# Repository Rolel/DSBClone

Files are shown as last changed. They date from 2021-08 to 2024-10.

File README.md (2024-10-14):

# DSB Clone
This is a replacement board for the SEGA Digital Sound Boards 1 and 2 used on several SEGA arcade games.

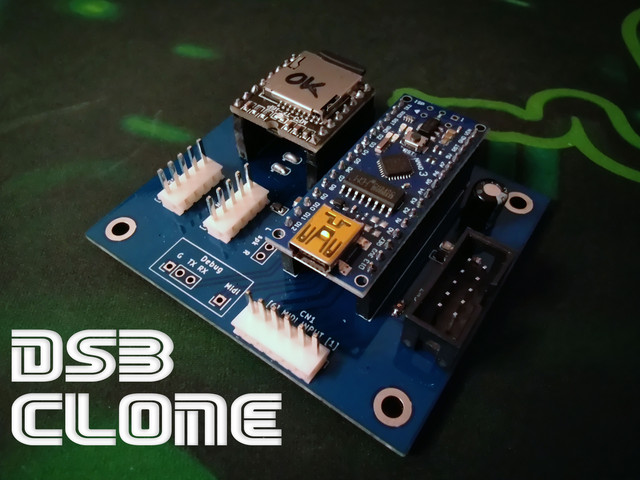
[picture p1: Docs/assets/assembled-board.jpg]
Assembled DSBClone board


# Historical background

The SEGA Digital Sound Boards 1 and 2 are dedicated to playing music (the BGMs) on several SEGA games. The music is stored in maskroms specific to each game. It is a card separate from the main stack of the game, sometimes located in its own cage.

They bear the following references: *837-10084 DIGITAL AUDIO BD SEGA 1993, 171-6614B PC BD, Sticker: 837-12941* and *837-12273 DIGITAL SOUND BD 2 SEGA 1995, 171-7165D PC BD, Sticker: 837-12273-92, Sticker: 837-13376*. These original cards are not very reliable and become difficult to find at a reasonable price.

They were used on the following games:

* First version (DSB1):
  * Daytona USA
  * Desert Tank
  * Manx TT Deluxe
  * Scud Race / Super GT (Model 3 Step 1.5)
  * Sega Rally Deluxe
  * Sega Touring Cars (Model 2C CRX)
  * Star Wars Arcade (Model 1)
  * Virtua Cop
  * Virtua Fighter
  * Virtua Racing
  * Wing Wars

*Please note that Daytona USA, Virtua Racing, Virtua Fighter, Wing War & Star Wars Arcade use DSB1 with an addon board in charge of playing sounds. The DSBclone doesn't handle this. As a result I suggest you avoid clone for such games and **DSB1 support is disabled by default in source code**.*

* Second version (DSB2):
  * Daytona 2
  * Lost World
  * Sega Rally 2
  * Spikeout
  * Spikeout FE
  * Star Wars Trilogy
  * Top Skater

# Features

* Playback of MP3 and WAV files stored on a microSD card
* Plug'n'Play: no modification of the wiring
* Track listing can be modified simply by renumbering the files
* Output volume identical to the original DSB
* Reprogrammable firmware: based on an Arduino Nano
* 24-bit DAC, DR 90dB, SNR 85 dB
* Protection by fuse and polarizers on the connectors
* 2 audio outputs with "JST SEGA" connector

In comparison with the original card:
* There is a slight latency (a few milliseconds) when starting the music. This can be understood if you pay attention with a twin that contains a DSB Sega and a DSB Clone. We can play on the MP3 to reset everything, or simply put two clones.
* The sound quality is much better: high quality MP3 / WAV replace the original 112kbits MPEG2.
* Possibility to customize the game's BGMs.

# Build 

## PCB

You can build the PCB with PCBway services. Upload the `DSBclone.kicad_pcb.zip` file to the "Quick order" tool and keep the default settings. That's all !

It can be even easier: use the shared project: https://www.pcbway.com/project/shareproject/DSB_Clone_replacement_for_SEGA_Digital_Sound_Boards_1_and_2_b2268928.html 

## BOM:
* U1: HCPL-0600 SOIC-8 optocoupler
* D1, D4: any diode that can handle 1A (T7 is ok)
* D2: 0805 led
* D3: 0805 1N4148, used to drop down DfPlayer voltage
* R1,R3,R5: 0805 1k resistor
* R2,R4: 0805 470o resistor
* F1: 0805 1A fuse
* DfPlayer: get the original one from reliable source (Mouser, Farnell...) and not an AliExpress clone.
* Arduino Nano: a 328p is ok.
* CN5: IDC 2x5 vertical connector
* CN6,7: JST B5P SH
* CN1: JST B6P SH 
* SPK, DBG, MidiRX: debug header, shouldn't be populated unless you want to develop

# Updating from release

Update procedure can be found in [Docs/Update.md](Docs/Update.md).

# Releases

Public releases can be found in the [Releases](Releases/) folder. Update procedure can be found in [Docs/Update.md](Docs/Update.md) documentation.

The "-debug.hex" releases have debugging enabled. You can hook a RS232 adapter to the debug pin on the board (default 115200bps, 8 data bits, 0 parity bit).

Public releases:

* 2021-08-29: 
  * Fix a bug on fadeout. 
  * Improvements on latency by filtering spam sent by games to the player.
* 2022-04-02: 
  * Change fadeout behavior; sound volume is now restored after fade.
  * Latency of MP3 player is tested on start; this improves latency.
* 2022-04-03:
  * Fix intro sound not being played on some MP3 players.
  * Fix advertisement BGM on Scud Race.
* 2022-04-05:
  * Fix a case where sound effects would affect BGM.
* 2022-04-06:
  * Reverted advertisement BGM played by DSB on Scud Race.
  * Track looping now working on Scud Race.
* 2022-04-16:
  * Track loop bugfix for Scud Race.
* 2022-12-04:
  * Removed support of DSB1 command set as they conflict with some DSB2 games.
* 2024-01-04:
  * Improvements on calibration for clone/original MP3 module. Releases available for DSB2, DSB1 & SpikeOut.
* 2024-08-24:
  * A special source code is proposed for SpikeOut FE. It compress sound volume to be closer to the original game.

# Installation

1. Prepare the SD card.

Any microSD card will do: between 60 and 150MB of space is sufficient. If you have an old 128 or 256MB card that's fine.

The audio files are to be placed in the "MP3" directory located at the root. Each file is preceded by 4 digits corresponding to the track number.
Bonus: the "1000_xxx.mp3" file is automatically read when the card is started. A cool way to have a jingle, music on hold, etc. Personally I put the "SEGAAAA" jingle 

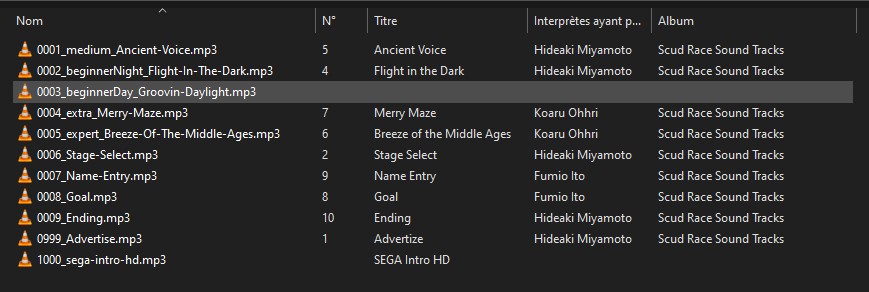
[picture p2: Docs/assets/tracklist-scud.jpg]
Track list example: SCUD Race
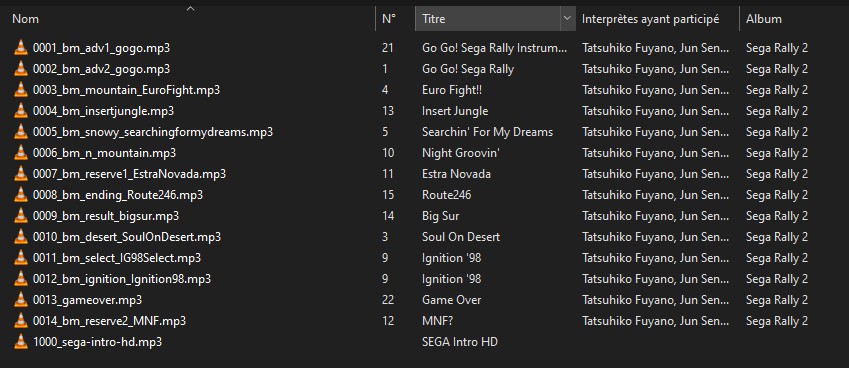
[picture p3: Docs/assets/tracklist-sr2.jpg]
Track list example: SEGA Rally 2
 

Several packs corresponding to the most common games are available. Here are those currently known:
* Sega Rally 2, CD quality from OST: https://segaretro.org/Sega_Rally_2_(album)
* Scud Race, CD quality from OST: https://segaretro.org/Scud_Race_Sound_Tracks
* Daytona2, CD quality from OST: https://segaretro.org/Daytona_USA_2_Sound_Tracks
* VirtuaRacing, dump arcade from Khinsider VGM
* In progress: Virtua Fighter, CD quality from OST: https://segaretro.org/Virtua_Fighter_&_Virtua_Fighter_2_Music_Tracks
* Numbers: all numbers from 1 to 100. This allows you to know which track is requested by the game without needing a computer.

As they are copyrighted materials they are not shared.

2. Connect to the arcade cabinet

It's plug'n'play without modifying the wiring:
* the black 10 pin socket for the power supply
* the 6-pin white socket for MIDI
* the white 5-pin socket(s) for the audio outputs

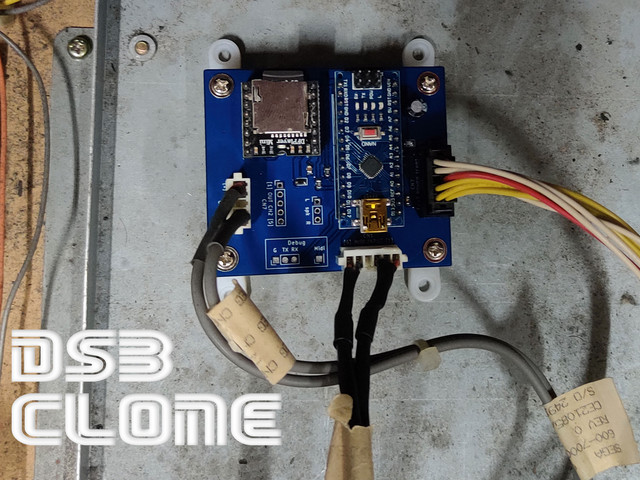
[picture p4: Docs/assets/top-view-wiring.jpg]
Top view wiring


# Ready to use board

You can buy a ready to use board on arcade forums like [Neo-Arcadia](https://www.neo-arcadia.com/forum/viewtopic.php?f=9&t=75510) (French) or [Arcade Projects](https://www.arcade-projects.com/threads/dsb-clone-digital-sound-board-sega.17832/) (English).

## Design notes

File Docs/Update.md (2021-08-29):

# Update procedure

## Requirements

* Windows computer.
* The hex file. It can be found in the [Release](../Releases/) folder in this repository.
* Xloader software. It can be fround in the [Tools](../Tools/) folder.
* USB cable to link the Arduino Nano to computer. This should be a USB A to mini-USB.

## Procedure

1. Unplug the Arduino from the DSBClone board.
2. Unzip all softwares on your computer.
3. Attach the Arduino to your computer using appropriate USB cable. Wait for the drivers to install. If it ask for drivers, search libusb0.dll in the Xloader archive.
4. Start XLoader.exe program.

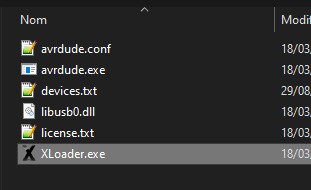
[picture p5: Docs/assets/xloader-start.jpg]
XLoader.exe


6. Setup Xloader

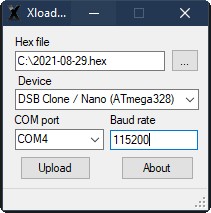
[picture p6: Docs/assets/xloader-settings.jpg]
XLoader Settings


    * Click on the 3 dots "..." to select the hex file.
    * Select "DSBClone" device.
    * Select COM port corresponding to the Arduino board.
    
7. Click "Upload".

During update a LED should blink on the Arduino. It usually takes 10s to update.

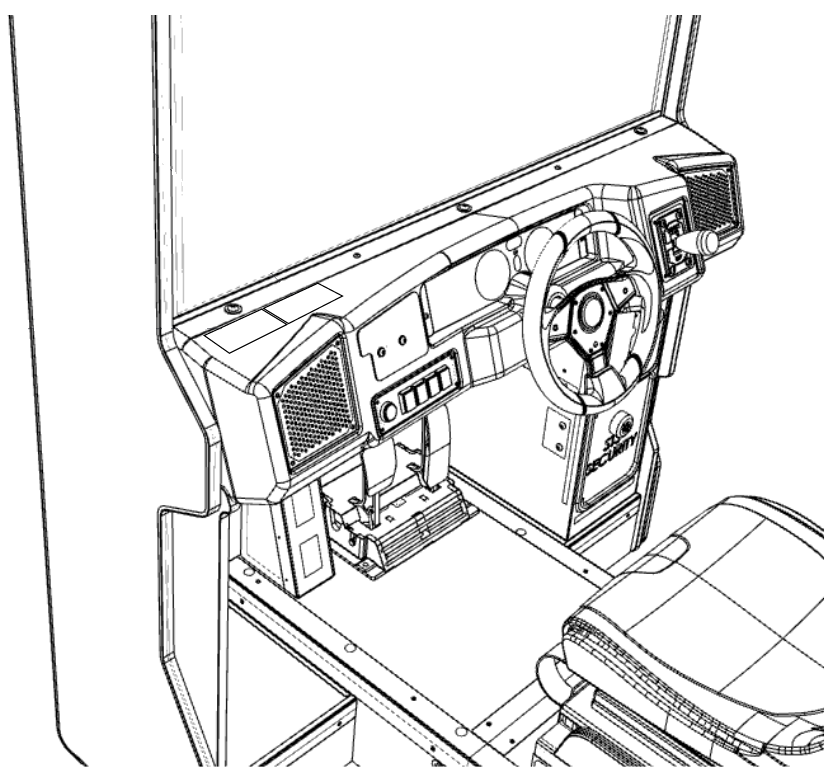
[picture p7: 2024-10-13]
Kicad/Racecab.png

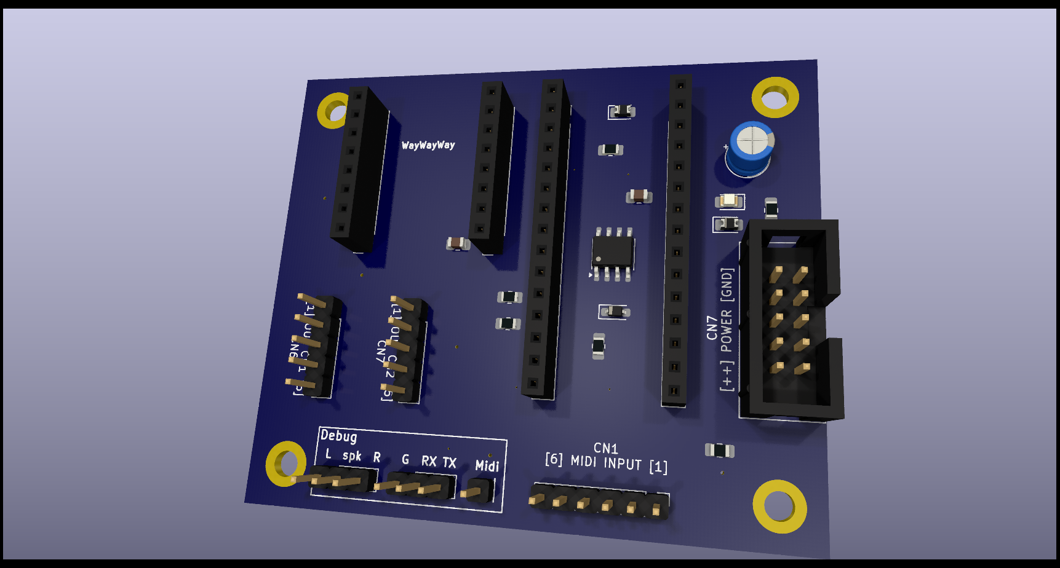
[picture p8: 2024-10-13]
Kicad/DSBclone.png

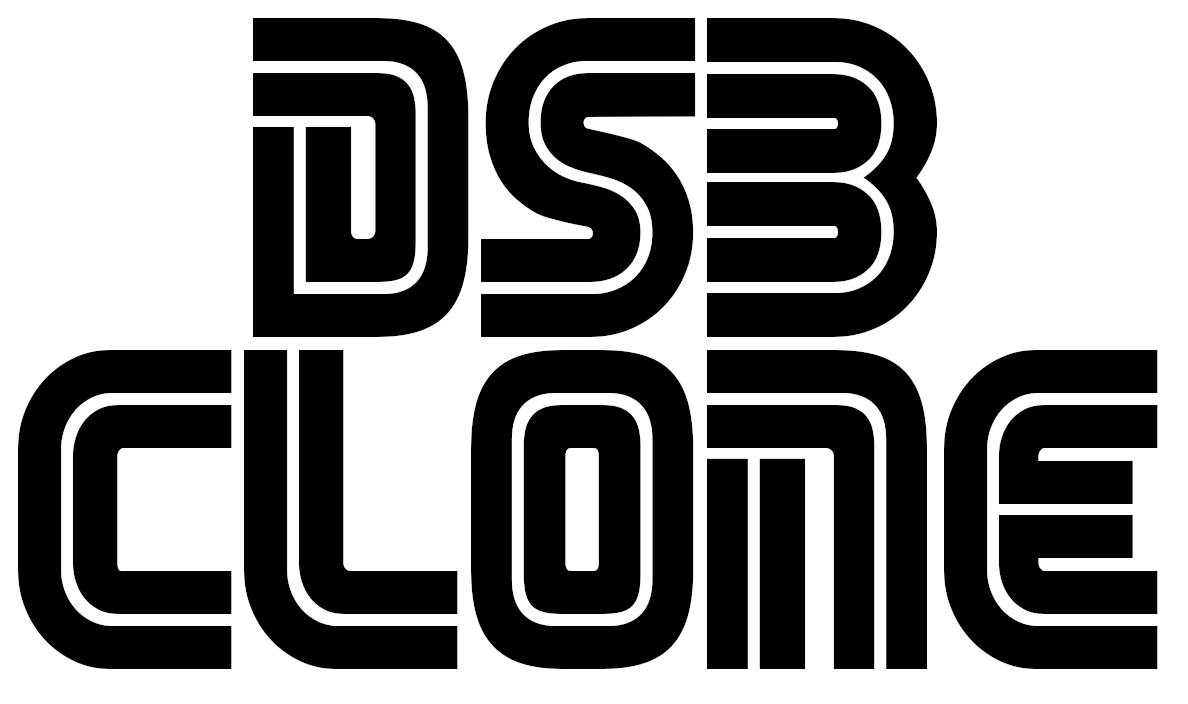
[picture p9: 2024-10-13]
Kicad/SEGA-dsbclone.png

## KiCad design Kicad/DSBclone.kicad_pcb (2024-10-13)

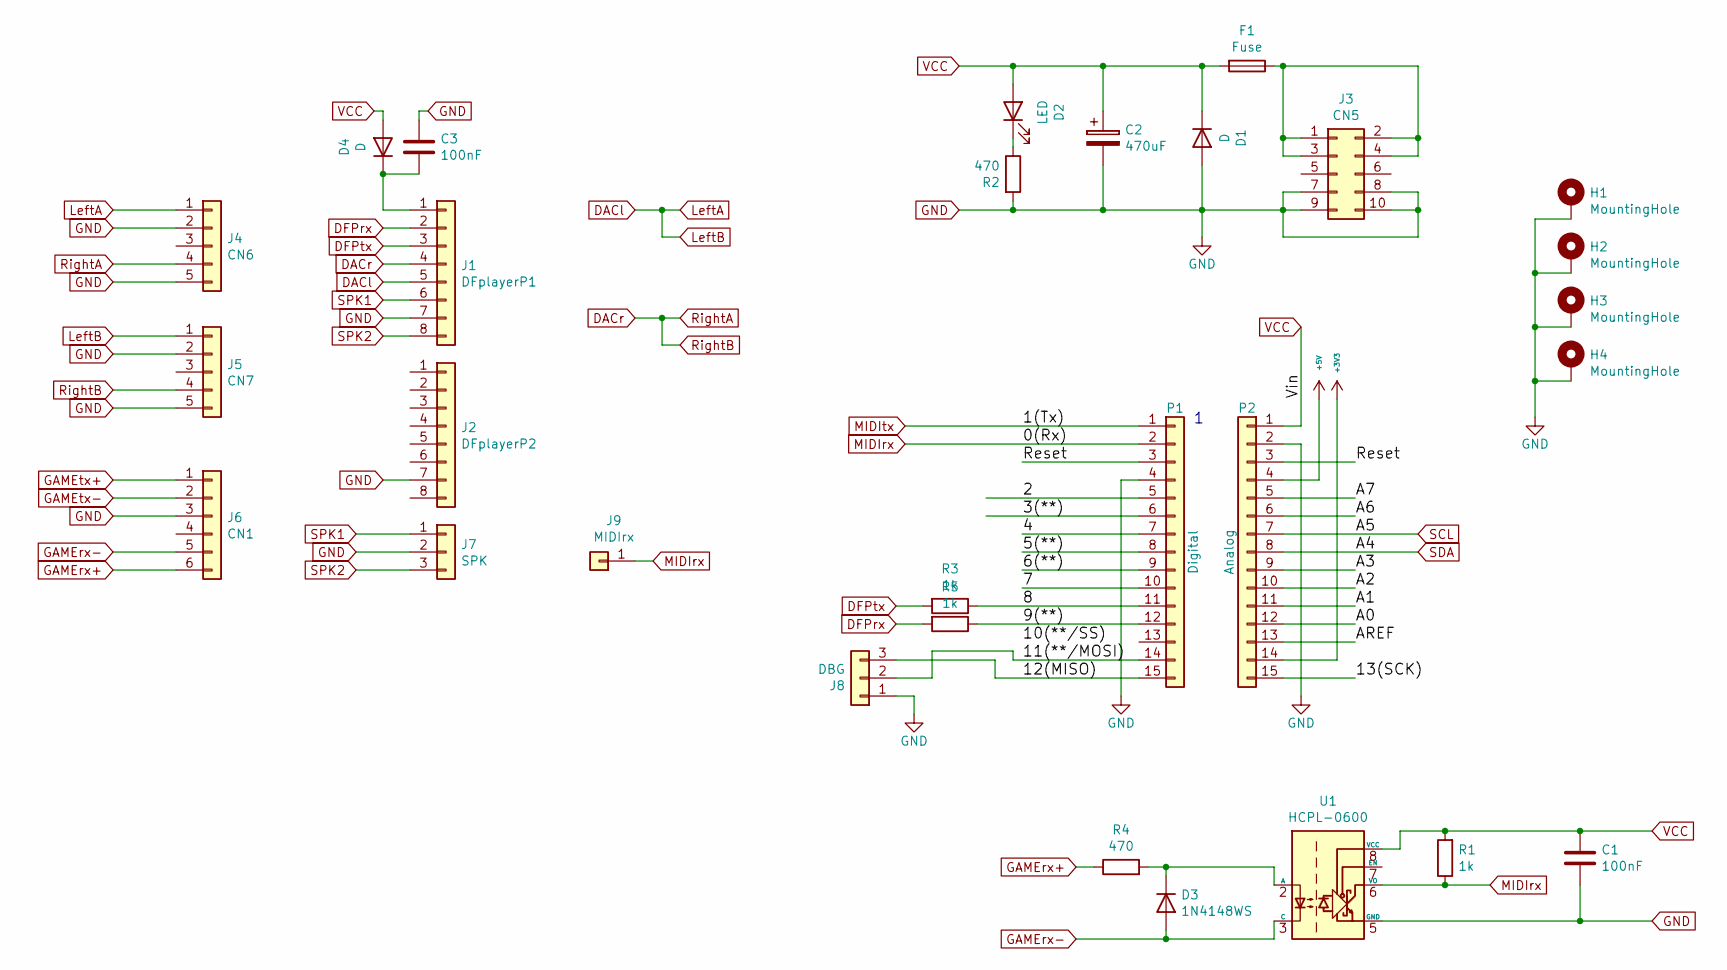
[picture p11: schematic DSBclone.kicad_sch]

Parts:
C1, C3: 100nF; C_0805_2012Metric_Pad1.18x1.45mm_HandSolder
C2: 470uF; CP_Radial_D5.0mm_P2.50mm
D1, D4: D; D_0805_2012Metric_Pad1.15x1.40mm_HandSolder
D2: LED; LED_0805_2012Metric_Pad1.15x1.40mm_HandSolder
D3: 1N4148WS; D_SOD-323_HandSoldering
F1: Fuse; Fuse_0805_2012Metric_Pad1.15x1.40mm_HandSolder
H1, H2, H3, H4: MountingHole; MountingHole_3.2mm_M3_DIN965_Pad
J1: DFplayerP1; PinSocket_1x08_P2.54mm_Vertical
J2: DFplayerP2; PinSocket_1x08_P2.54mm_Vertical
J3: CN5; IDC-Header_2x05_P2.54mm_Vertical
J4: CN6; PinHeader_1x05_P2.54mm_Vertical
J5: CN7; PinHeader_1x05_P2.54mm_Vertical
J6: CN1; PinHeader_1x06_P2.54mm_Vertical
J7: SPK; PinHeader_1x03_P2.54mm_Vertical
J8: DBG; PinHeader_1x03_P2.54mm_Vertical
J9: MIDIrx; PinHeader_1x01_P2.54mm_Vertical
P1: Digital; PinSocket_1x15_P2.54mm_Vertical
P2: Analog; PinSocket_1x15_P2.54mm_Vertical
R1, R3, R5: 1k; R_0805_2012Metric_Pad1.20x1.40mm_HandSolder
R2, R4: 470; R_0805_2012Metric_Pad1.20x1.40mm_HandSolder
U1: HCPL-0600; SOIC-8_3.9x4.9mm_P1.27mm

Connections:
+3V3: P2.14
+5V: P2.4
/2: P1.5
/3(**): P1.6
/4: P1.7
/5(**): P1.8
/6(**): P1.9
/7: P1.10
/8: P1.11, R3.1
/9(**): P1.12, R5.1
/11(**/MOSI): J8.2, P1.14
/12(MISO): J8.3, P1.15
/13(SCK): P2.15
/A0: P2.12
/A1: P2.11
/A2: P2.10
/A3: P2.9
/A6: P2.6
/A7: P2.5
/AREF: P2.13
/Reset: P1.3, P2.3
DACl: J1.5, J4.1, J5.1
DACr: J1.4, J4.4, J5.4
DFPrx: J1.2, R5.2
DFPtx: J1.3, R3.2
GAMErx+: J6.6, R4.1
GAMErx-: D3.2 (A), J6.5, U1.3 (C)
GAMEtx+: J6.1
GAMEtx-: J6.2
GND: C1.2, C2.2, C3.1, D1.2 (A), H1.1, H2.1, H3.1, H4.1, J1.7, J2.7, J3.7, J3.8, J3.9, J3.10, J4.2, J4.5, J5.2, J5.5, J6.3, J7.2, J8.1, P1.4, P2.2, R2.2, U1.5 (GND)
MIDIrx: J9.1, P1.2, R1.1, U1.6 (VO)
MIDItx: P1.1
unnamed: D2.1 (K), R2.1
unnamed: D3.1 (K), R4.2, U1.2 (A)
unnamed: C3.2, D4.1 (K), J1.1
unnamed: F1.1, J3.1, J3.2, J3.3, J3.4
SCL: P2.7
SDA: P2.8
SPK1: J1.6, J7.1
SPK2: J1.8, J7.3
VCC: C1.1, C2.1, D1.1 (K), D2.2 (A), D4.2 (A), F1.2, P2.1, R1.2, U1.8 (VCC)

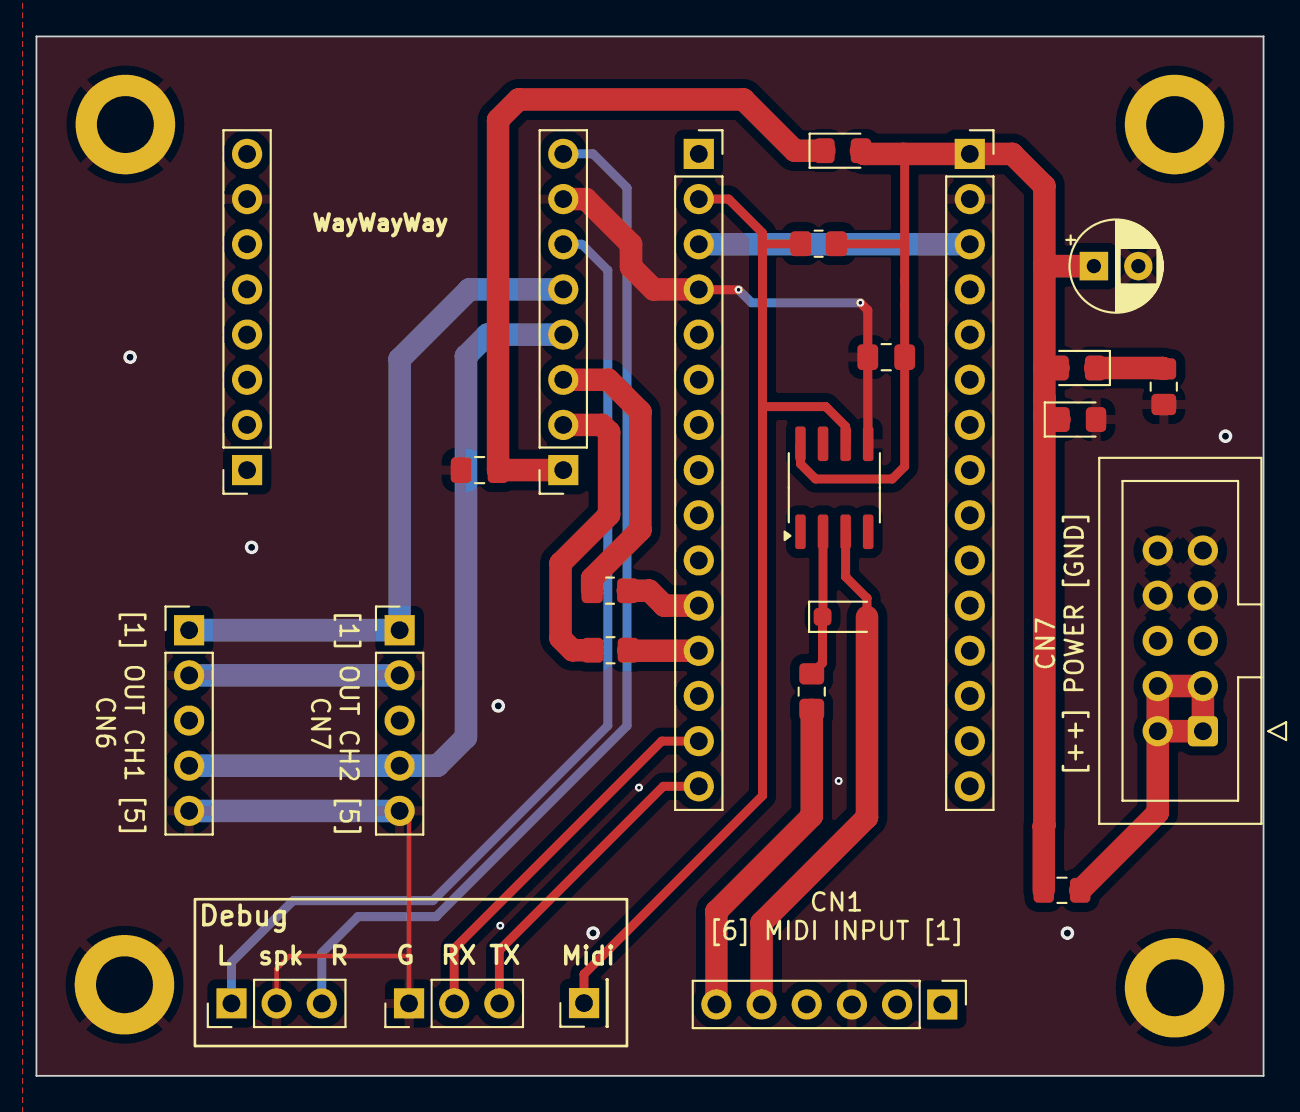
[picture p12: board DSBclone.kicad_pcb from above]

Board: 2 copper layers, 69.0 x 58.4 mm, 29 parts (0 on the bottom side), 20 nets.

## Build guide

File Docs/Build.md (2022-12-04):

# Build from sources

## Hardware
PCB details not public yet but please note that all official DSBclone have been distributed with an Arduino Nano equipped with ATmega328 and MiniCore bootloader.

## Software requirements

* Arduino IDE: it has been successfully tested with 1.8/2.0
* MiniCore bootloader recommended. Board config is located here: https://mcudude.github.io/MiniCore/package_MCUdude_MiniCore_index.json and full instructions here: https://github.com/MCUdude/MiniCore
* Some third parties libraries are used and may need to be installed in "Tools/Manage Libraries"
    * https://github.com/PaulStoffregen/AltSoftSerial
    * https://github.com/NitrofMtl/TimeOut
    * https://github.com/FortySevenEffects/arduino_midi_library (1) see note
    * https://github.com/Makuna/DFMiniMp3 (1) see note

(1) MIDI and DFminiMP3 libraries have been modified to workaround custom MIDI protocol by SEGA and slow unofficial MP3 modules. A modified version is included in the project.

## Board configuration

1. In Arduino IDE, menu Tools/Board, select "MiniCore / ATmega328".
2. All other settings are default.

## Uploading

Compilation and uploading are done as usual. You refer to official Arduino IDE documentation: https://support.arduino.cc/hc/en-us/articles/4733418441116-Upload-a-sketch-in-Arduino-IDE

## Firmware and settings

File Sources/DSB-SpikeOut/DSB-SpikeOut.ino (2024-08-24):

  /*
   Use:
   https://github.com/FortySevenEffects/arduino_midi_library
   https://github.com/Makuna/DFMiniMp3
   https://github.com/PaulStoffregen/AltSoftSerial
   https://github.com/NitrofMtl/TimeOut

  How to organize SD card:
      every files in MP3 folder
      file should be name XXXX-whatever.mp3 with XXXX being the track number with leading 0
      file 1000-whatever.mp3 is played on boot

  Note on MIDI Library:
      Midi protocol is not respected by VirtuaRacing DSB, as a result we need to "hack" the library.
      Correct NoteOff and ControlChange messages are 3 bytes MIDI, but only 2 with VirtuaRacing.
      MIDI.hpp file should be modified with this code at line 896:
        // HACK for Virtua Racing
        if (mPendingMessage[0] == 129 || mPendingMessage[0] == 176) {
                mPendingMessageExpectedLength = 2;
        }

        
  Note on DFMiniMp3 Library:
      By default library keep 50ms space between 2 commands.
      Clone chip may need larger delay, up to 150ms.
      Library has been modified to allow this delay to be set from code.
*/

#include "LibMod/DFMiniMp3.h"
#include "LibMod/MIDI/MIDI.h"
#include <TimeOut.h>
#include <SoftwareSerial.h>
#include <AltSoftSerial.h>



// Enable debug messages over serial
// #define DEBUG 

// Enable DSB1 support
#define ENABLE_DSB1 false

// Enable SpikeOut patches
#define ENABLE_SPIKEOUT true

// This is the minimal delay between 2 dfPlayer commands
#define DFPLAYER_SENDSPACE 30

// Init some global variable
byte soundVolume = 20; // initial volume of dfPlayer
byte soundTable[128] = {
  // Repeating each value 2 times from 0 to 5
  0, 0, // 0 = 0 => 1
  1, 1, // 1 = 2 => 3
  2, 2, // 2 = 4 => 5
  3, 3, // 3 = 6 => 7
  4, 4, // 4 = 8 => 9
  5, 5, // 5 = 10 => 11
  
  // Repeating each value 3 times from 6 to 11
  6, 6, 6, // 6 = 12 => 14
  7, 7, 7, // 7 = 15 => 17
  8, 8, 8, // 8 = 18 => 20
  9, 9, 9, // 9 = 21 => 23
  10, 10, 10, // 10 = 24 => 26
  11, 11, 11, // 11 = 27 => 29
  
  // Repeating each value 4 times from 12 to 17
  12, 12, 12, 12, // 12 = 30 => 33
  13, 13, 13, 13, // 13 = 34 => 37
  14, 14, 14, 14, // 14 = 38 => 41
  15, 15, 15, 15, // 15 = 42 => 45
  16, 16, 16, 16, // 16 = 46 => 49
  17, 17, 17, 17, // 17 = 50 => 53
  
  // Repeating each value 5 times from 18 to 25
  18, 18, 18, 18, 18, // 18 = 54 => 58
  19, 19, 19, 19, 19, // 19 = 59 => 63
  20, 20, 20, 20, 20, // 20 = 64 => 68
  21, 21, 21, 21, 21, // 21 = 69 => 73
  22, 22, 22, 22, 22, // 22 = 74 => 78
  23, 23, 23, 23, 23, // 23 = 79 => 83
  24, 24, 24, 24, 24, // 24 = 84 => 88
  25, 25, 25, 25, 25, // 25 = 89 => 93

  // Repeating each value 6 times from 26 onwards
  26, 26, 26, 26, 26, 26, // 26 = 94 => 99
  27, 27, 27, 27, 27, 27, // 27 = 100 => 105
  28, 28, 28, 28, 28, 28, // 28 = 106 => 111
  29, 29, 29, 29, 29, 29, // 29 = 112 => 117
  30, 30, 30, 30, 30, 30, // 30 = 118 => 123
  31, 31, 31, 31  // 31 = 124 => 127 (Note: Adjusted to fit within the limit)
};




uint16_t errorCounter = 0; // global counter used to track communication error with dfPlayer
byte lastCommand = 0; // last command sent to arduino, see LastCommandType enum
enum LastCommandType: byte
{
    Play     = 1,
    Stop     = 2,
    FadeOut  = 3,
    Reset    = 4,
    Volume   = 5,
};


// UARTs setup
struct DSB2Settings : public midi::DefaultSettings
{
  static const long BaudRate = 31250;
};
MIDI_CREATE_CUSTOM_INSTANCE(HardwareSerial, Serial, MIDI, DSB2Settings);


AltSoftSerial softSerial; // Used for MP3Player - RX8, TX9 (and 10 unusable)

#ifdef DEBUG
SoftwareSerial softSerialDebugger(11, 12); // Used for debugger
#endif

class Mp3Notify;
// typedef DFMiniMp3<AltSoftSerial, Mp3Notify, Mp3ChipMH2024K16SS> DfMp3;
typedef DFMiniMp3<AltSoftSerial, Mp3Notify, Mp3ChipOriginal> DfMp3;

class Mp3Notify
{
#ifdef DEBUG
  public:
    static void OnError(DfMp3& mp3, uint16_t errorCode) {
      errorCounter++;
      // see DfMp3_Error for code meaning
      switch (errorCode) {
        case 1:
          softSerialDebugger.println(F("DFPlayer: DfMp3_Error_Busy = 1 - (see chip documentation) Usually the media was not found."));
          break;
        case 2:
          softSerialDebugger.println(F("DFPlayer: DfMp3_Error_Sleeping = 2 - (see chip documentation) The chip is in sleep mode."));
          break;
        case 3:
          // Serial error ? We increase delay between 2 commands
          mp3.increaseSendSpace();
          digitalWrite(LED_BUILTIN, !digitalRead(LED_BUILTIN));
          softSerialDebugger.println(F("DFPlayer: DfMp3_Error_softSerialDebuggerWrongStack = 3 - Serial communication error (see chip documentation)"));
          break;
        case 4:
          softSerialDebugger.println(F("DFPlayer: DfMp3_Error_CheckSumNotMatch = 4 - (see chip documentation) Communications error on the hardware level. Check wiring and GND connections."));
          break;
        case 5:
          softSerialDebugger.println(F("DFPlayer: DfMp3_Error_FileIndexOut = 5 - (see chip documentation) File index out of bounds."));
          break;
        case 6:
          softSerialDebugger.println(F("DFPlayer: DfMp3_Error_FileMismatch = 6 - (see chip documentation) Can not find file."));
          break;
        case 7:
          softSerialDebugger.println(F("DFPlayer: DfMp3_Error_Advertise = 7 - (see chip documentation) In advertisement."));
          break;
        default:
          Serial.print(F("DFPlayer: Unknown error code = "));
          Serial.println(errorCode);
          break;
      }
    }

    static void OnPlayFinished(DfMp3& mp3, DfMp3_PlaySources source, uint16_t track) {
      softSerialDebugger.print(F("DFPlayer: Play finished for #"));
      softSerialDebugger.println(track);
    }
    static void OnPlaySourceOnline(DfMp3& mp3, DfMp3_PlaySources source) {
      PrintlnSourceAction(source, "online");
    }
    static void OnPlaySourceInserted(DfMp3& mp3, DfMp3_PlaySources source) {
      PrintlnSourceAction(source, "inserted");
    }
    static void OnPlaySourceRemoved(DfMp3& mp3, DfMp3_PlaySources source) {
      PrintlnSourceAction(source, "removed");
    }
    static void PrintlnSourceAction(DfMp3_PlaySources source, const char* action)
    {
      if (source & DfMp3_PlaySources_Sd) { softSerialDebugger.print(F("DFPlayer: SD Card, ")); }
      if (source & DfMp3_PlaySources_Usb) { softSerialDebugger.print(F("DFPlayer: USB Disk, ")); }
      if (source & DfMp3_PlaySources_Flash) { softSerialDebugger.print(F("DFPlayer: Flash, ")); }
      softSerialDebugger.println(action);
    }
#else

  public:
    static void OnError(DfMp3& mp3, uint16_t errorCode) {
      errorCounter++;
      if (errorCode == 3) {
        // Serial error ? We increase delay between 2 commands
        mp3.increaseSendSpace();
        digitalWrite(LED_BUILTIN, !digitalRead(LED_BUILTIN));
      }
    }
    static void OnPlayFinished(DfMp3& mp3, DfMp3_PlaySources source, uint16_t track) {}
    static void OnPlaySourceOnline(DfMp3& mp3, DfMp3_PlaySources source) {}
    static void OnPlaySourceInserted(DfMp3& mp3, DfMp3_PlaySources source) {}
    static void OnPlaySourceRemoved(DfMp3& mp3, DfMp3_PlaySources source) {}
#endif
};

DfMp3 dfPlayer(softSerial);

TimeOut repeatTimeout;

void setup() {
  int result, i;
  
  pinMode(LED_BUILTIN, OUTPUT);

  #ifdef DEBUG
    softSerialDebugger.begin(115200);
    softSerialDebugger.println(F("DSB Clone - debug interface started"));
    softSerialDebugger.println("Built on " __DATE__ " at " __TIME__);
    softSerialDebugger.println(F("STARTUP: Starting MP3 player"));
  #endif
  // Init the mp3 module with a delay between commands
  dfPlayer.begin();
  dfPlayer.setSendSpace(DFPLAYER_SENDSPACE);

  // Boot procedure for some picky module: reset, wait for SD
  dfPlayer.reset();
  waitMilliseconds(500);
  // Be silent and use SD
  dfPlayer.setVolume(0);
  dfPlayer.setPlaybackSource(DfMp3_PlaySource_Sd);
  i = 0;
  do{
      waitMilliseconds(100);
      result=dfPlayer.isOnline();
      i++;
  } while (result==false && i < 20);

  #ifdef DEBUG
    softSerialDebugger.println(F("STARTUP: Calibrate send space."));
  #endif
  calibrateSendSpace();
  
  #ifdef DEBUG
    softSerialDebugger.print(F("STARTUP: Setting volume to "));
    softSerialDebugger.println(soundVolume);
  #endif
  dfPlayer.setVolume(soundVolume);
  #ifdef DEBUG
    softSerialDebugger.println(F("STARTUP: Setting EQ"));
  #endif
  dfPlayer.setEq(DfMp3_Eq_Bass);
  waitMilliseconds(500);
   
  dfPlayer.playMp3FolderTrack(1000);
  waitMilliseconds(3000);
  #ifdef DEBUG
    softSerialDebugger.println(F("STARTUP: MP3 player started"));
  #endif

  /* Callbacks !
    https://github.com/FortySevenEffects/arduino_midi_library/wiki/Using-Callbacks
    MIDI.setHandleNoteOn(handleNoteOn);

    List of MIDI messages:
    https://www.midi.org/specifications-old/item/table-1-summary-of-midi-message
  */
  MIDI.setHandleAfterTouchPoly(handleAfterTouchPoly);
  MIDI.setHandleSystemReset(handleSystemReset);
  if (ENABLE_DSB1) {
    MIDI.setHandleControlChange(handleControlChange);
    MIDI.setHandleNoteOff(handleNoteOff);
  }
  #ifdef DEBUG
    softSerialDebugger.println(F("STARTUP: Starting MIDI interface"));
  #endif
  // Listen to every MIDI channels
  MIDI.begin(MIDI_CHANNEL_OMNI);

  
  #ifdef DEBUG
    softSerialDebugger.println(F("STARTUP: MIDI interface listening"));
    softSerialDebugger.println(F("STARTUP: System ready"));
  #endif
}

void loop() {
  // Maybe not call it on every loop ?
  dfPlayer.loop();

  // Timeout handler monitor all callback
  TimeOut::handler();

  // Just read as fast as we can to get callback working
  if (MIDI.read()) {
    // Blink LED on every message
    digitalWrite(LED_BUILTIN, !digitalRead(LED_BUILTIN));
  }
}


/**
   Most message are Aftertouch Polyphonic, with one exception for the system reset
     DSB1 uses channels 15 (xAE/d174), 16 (xAF/d175) (Scud Race)
     DSB1 on virtua racing start messages with channel 17 (xB0/d176) (Virtua Racing)
     DSB2 uses channel 15 (xAE/d174)
   We'll simply ignore channel information and do not filter it.
*/
void handleAfterTouchPoly(byte channel, byte note, byte pressure) {
  /*
    Play Command: it starts a BGM.
     Note is a sound type: BGM, effect, voices...
     Pressure is the track.

    # About "channel"
    No game use channel 1-14; only 15 and 16 are used.
    Commands always begin with 174 (channel 15), 175 (channel 16) or 176 (another MIDI command).
    It's supposed 174 is play and 175 is loop play.

    # About "note"
    Most games use note x10/d16 for BGM, but some like ScudRace use x6F/d111.
    We need to filter because a lot of other note are sent for sound effect. Trying to start them would kill BGM.
    DFplayer handles up to 99 folders. It means using note as a folder name is not possible for ScudRace.

    # About "pressure"
    For every game pressure = 0 means STOP but for Scud Race there is a track: the advertisement BGM.
    As a result we "rewrite" value to 255 if game is Scud Race, because track 0 can't be played on DFplayer.
    
    # Example: on Sega Rally 2
    BGM music start at 16:1 and goes to 16:14 (also, there is no 4 in test menu)
    Playing BGM 0 is a way to stop current playing song
    Note from 17:* to 26:* are sound effects and voices
    
    # Example: on Scud Race
    BGM music start at 111:1 and goes to 111:9
    Playing BGM 0 is a way to stop current playing song
  */
  if (channel < 15) {
    // Channel is not 15/16
    return;
  }
  
  if (note == 16 || note == 111) {    
    if (pressure > 0) {
      
      dfPlayer.playMp3FolderTrack(pressure);      
      lastCommand = LastCommandType::Play;

      // Activate repeat if channel 16
      if (channel == 16 || ENABLE_SPIKEOUT) {
        // a delayed setRepeatPlayCurrentTrack
        repeatTimeout.timeOut(500, setRepeat, TIMEOUT::UNDELETABLE);
        // dfPlayer.setRepeatPlayCurrentTrack(true);
      }
      
      #ifdef DEBUG
        softSerialDebugger.print(F("CMD: BGM #"));
        softSerialDebugger.println(pressure);
      #endif
    } else {
      dfPlayer.stop();
      lastCommand = LastCommandType::Stop;
      #ifdef DEBUG
        softSerialDebugger.println(F("CMD: BGM #0 STOP"));
      #endif
    }
  }

  /*
    // On Sega Rally 2 commands from d17:* to d26:* are sound effects and voices
    if (note > 16 && note < 27 && pressure > 0) {
    #ifdef DEBUG
      softSerialDebugger.print(F("CMD: sound effect #"));
      softSerialDebugger.print(note);
      softSerialDebugger.print(F(" #"));
      softSerialDebugger.println(pressure);
    #endif
    }
  */


  /*
    Volume Command: set the sound volume

    Volume commands are the same for every DSB. It uses the note 01 or 02 and pressure is volume.

    On Sega Rally 2
     Every BGM play command is preceeded by a sound volume command
     Goes from 0 to 15 in service menu; from 0 to 90 in MIDI messages (14 and 15 are both 90)
     0:0, 1:12, 2:18, 3:24, 4:30, 5:36, 6:42, 7:48, 8:54, 9:60, 10:66, 11:72, 12:78, 13:84, 14:90, 15:90
     Volume on DFplayer goes from 0 to 30; but 21 already too much powerfull so limiting from 0 to 22 is ok => we divide command by 4.
     Why 4 ? Because it's easy for a CPU to divide by 4, it's only a bitshift
  */
  if (note == 1 || note == 2) {
    // DFPlayer handles volume values from 0 to 30 , we'll go up to 22.5 by dividing input command (90 max) by 4
    // TODO: replace division by a lookup table for speed ?
    // byte TMPsoundVolume = pressure >> 2;
    byte TMPsoundVolume = soundTable[pressure];

    #ifdef DEBUG
      softSerialDebugger.print(F("CMD: Volume change. Value: "));
      softSerialDebugger.print(pressure);
      softSerialDebugger.print(F(" => Game setting: "));
      softSerialDebugger.println(TMPsoundVolume);
    #endif
    
    // New volume value is compared with old one. If it's the same we avoid sending the command again.
    if (TMPsoundVolume != soundVolume) {
      dfPlayer.setVolume(TMPsoundVolume);
      soundVolume = TMPsoundVolume;
    } else {
      #ifdef DEBUG
        softSerialDebugger.println(F("INFO: Not sent to dfPlayer because volume was already the same"));
      #endif
    }
    
    lastCommand = LastCommandType::Volume;
  }

  /*
    Fadeout Command: stop a BGM with a fadeout.

    Most DSB use note 3, but some use note 4 to start a fadeout.
    It's not clear what the pressure do. Maybe a speed of fadeout ?

    DFplayer can't do fadeout but we can fake it by changing volume.

    Example: on Sega Rally 2 it happens after intro.
  */
  if (note == 3 || note == 4) {
    #ifdef DEBUG
      softSerialDebugger.print(F("CMD: Fadeout "));
      softSerialDebugger.println(pressure);
    #endif
    fadeOut(pressure >> 2);
    lastCommand = LastCommandType::FadeOut;
  }
}

/**
   Some system reset command are issued from time on time
   It uses the MIDI system reset command.
*/
void handleSystemReset(void) {
  #ifdef DEBUG
    softSerialDebugger.println(F("CMD: System reset command received"));
  #endif
  // We do not reset MP3 player as it "cracks" in speaker and cause 600ms lag, only stop playing
  dfPlayer.stop();
  lastCommand = LastCommandType::Reset;
}


/**
   The ControlChange is used by VirtuaFighter for Fadeout:
     status = xBE/d190 (channel 15)
     number = x18/d24
     value change according to speed = x20/d32,x30/d48,x40/d64,x50/d80

   This is also used by Virtua Racing but in a bugged version: the play sound action is a control change with only one data byte (instead of two)
     status = xB0/d176
     number = x00/d00 The track to play
     no value byte !
   This implie we need to hack MIDI library so statusbyte 176 is declared as two bytes instead of three
*/
void handleControlChange(byte channel, byte number, byte value) {
  // VirtuaFighter Fadeout
  // Statusbyte 190 = channel 15 (1-16)
  if (channel == 15 && number == 24) {
    #ifdef DEBUG
      softSerialDebugger.print(F("CMD: FadeOut VirtuaFighter "));
      softSerialDebugger.println(number);
    #endif
    fadeOut(value / 4);
    lastCommand = LastCommandType::FadeOut;
  }

  // Virtua Racing play
  // Statusbyte 176 = channel 1 (1-16)
  if (channel == 1) {
    // Custom hacked command for Virtua Racing
    dfPlayer.playMp3FolderTrack(number);
    lastCommand = LastCommandType::Play;
    #ifdef DEBUG
      softSerialDebugger.print(F("CMD: ControlChange VirtuaRacing: BGM #"));
      softSerialDebugger.println(number);
    #endif
  }
}

/**
   The NoteOff is used by Virtua Racing but in a bugged version: the stop sound action is a noteoff with only one data byte (instead of two)
     status = x81/d129
     number = x00/d00 always 0
     no value byte !
   This implie we need to hack MIDI library so statusbyte 129 is declared as two bytes instead of three
*/
void handleNoteOff(byte inChannel, byte inPitch, byte inVelocity) {
  if (inChannel == 2 && inPitch == 0) {
    dfPlayer.stop();
    lastCommand = LastCommandType::Stop;
    #ifdef DEBUG
      softSerialDebugger.println(F("CMD: NoteOff VirtuaRacing : STOP sound"));
    #endif
  }
}



/**
 * Do a fade out by changing volume to 0 then sending stop.
 * Volume is restored after
 * 
 * byte delay = delay in loop
*/
void fadeOut(byte delayValue) {

  // Some games are spamming fade out command, we skip next messages
  if (lastCommand == LastCommandType::FadeOut) {
  #ifdef DEBUG
    softSerialDebugger.print(F("Fading: previous cmd was already a fadeout, no fade"));
  #endif
    return;
  }

  #ifdef DEBUG
    softSerialDebugger.print(F("Fading:"));
  #endif
  // We use a local variable so we can restore sound to previous value.
  // Some games (like scud race) don't set sound volume on every play so we need to restore after a fadeout.
  byte fadeSoundVolume = soundVolume;

  // Reduce slowly to level 1
  while (fadeSoundVolume > 1) {
    fadeSoundVolume--;
    dfPlayer.setVolume(fadeSoundVolume);
    waitMilliseconds(delayValue);
    #ifdef DEBUG
      softSerialDebugger.print(F(" "));
      softSerialDebugger.print(fadeSoundVolume);
    #endif
  }

  // At the end we stop play, wait and restore volume
  dfPlayer.stop();
  waitMilliseconds(50);
  dfPlayer.setVolume(soundVolume);
  
  #ifdef DEBUG
    softSerialDebugger.println(F(" end fadeout"));
  #endif
}

/**
 * A simple callback function to repeat current track
 */
void setRepeat()
{
  dfPlayer.setRepeatPlayCurrentTrack(true);
}

/**
 * This increase communication delay with dfPlayer until we get no error
 */
void calibrateSendSpace() {
  byte okLoop = 0;
  uint16_t status = 0;
  
  do {
    // Do the test: stop+start
    dfPlayer.stop();
    dfPlayer.playRandomTrackFromAll();
    // getStatus doesn't work on MH2024K24SS :/
    status = dfPlayer.getStatus();
    // Should be playing music without error
    if (status == 0 || status == 512 || status == 529) {
      // Increase space between 2 commands and reset loop counter
      dfPlayer.increaseSendSpace();
      okLoop = 0;
    } else {
      okLoop++;
    } 
    
  #ifdef DEBUG
    softSerialDebugger.print(F("Calibration (status/errors/ok): "));
    softSerialDebugger.printf("%d status / %d errors / %d OKloop.\n\r", status, errorCounter, okLoop);
  #endif
  // 10 consecutive success ? We are calibrated !
  } while(okLoop < 10);
  // A little bit more to be secure
  dfPlayer.increaseSendSpace();
  // Don't forget to stop at the end
  dfPlayer.stop();
  #ifdef DEBUG
    softSerialDebugger.printf("Final value: %d ms.\n\r", dfPlayer.getSendSpace());
  #endif
}


/**
 * A blocking wait function
 */
void waitMilliseconds(uint16_t msWait)
{
  uint32_t start = millis();
  
  while ((millis() - start) < msWait)
  {
    dfPlayer.loop(); 
    delay(1);
  }
}

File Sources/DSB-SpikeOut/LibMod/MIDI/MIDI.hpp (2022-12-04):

/*!
 *  @file       MIDI.hpp
 *  Project     Arduino MIDI Library
 *  @brief      MIDI Library for the Arduino - Inline implementations
 *  @author     Francois Best, lathoub
 *  @date       24/02/11
 *  @license    MIT - Copyright (c) 2015 Francois Best
 *
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
 * THE SOFTWARE IS PROVIDED "AS IS", WITHOUT WARRANTY OF ANY KIND, EXPRESS OR
 * IMPLIED, INCLUDING BUT NOT LIMITED TO THE WARRANTIES OF MERCHANTABILITY,
 * FITNESS FOR A PARTICULAR PURPOSE AND NONINFRINGEMENT. IN NO EVENT SHALL THE
 * AUTHORS OR COPYRIGHT HOLDERS BE LIABLE FOR ANY CLAIM, DAMAGES OR OTHER
 * LIABILITY, WHETHER IN AN ACTION OF CONTRACT, TORT OR OTHERWISE, ARISING FROM,
 * OUT OF OR IN CONNECTION WITH THE SOFTWARE OR THE USE OR OTHER DEALINGS IN
 * THE SOFTWARE.
 */

#pragma once

BEGIN_MIDI_NAMESPACE

/// \brief Constructor for MidiInterface.
template<class Transport, class Settings, class Platform>
inline MidiInterface<Transport, Settings, Platform>::MidiInterface(Transport& inTransport)
    : mTransport(inTransport)
    , mInputChannel(0)
    , mRunningStatus_RX(InvalidType)
    , mRunningStatus_TX(InvalidType)
    , mPendingMessageExpectedLength(0)
    , mPendingMessageIndex(0)
    , mCurrentRpnNumber(0xffff)
    , mCurrentNrpnNumber(0xffff)
    , mThruActivated(true)
    , mThruFilterMode(Thru::Full)
    , mLastMessageSentTime(0)
    , mLastMessageReceivedTime(0)
    , mSenderActiveSensingPeriodicity(0)
    , mReceiverActiveSensingActivated(false)
    , mLastError(0)
{
        mSenderActiveSensingPeriodicity = Settings::SenderActiveSensingPeriodicity;
}

/*! \brief Destructor for MidiInterface.

 This is not really useful for the Arduino, as it is never called...
 */
template<class Transport, class Settings, class Platform>
inline MidiInterface<Transport, Settings, Platform>::~MidiInterface()
{
}

// -----------------------------------------------------------------------------

/*! \brief Call the begin method in the setup() function of the Arduino.

 All parameters are set to their default values:
 - Input channel set to 1 if no value is specified
 - Full thru mirroring
 */
template<class Transport, class Settings, class Platform>
void MidiInterface<Transport, Settings, Platform>::begin(Channel inChannel)
{
    // Initialise the Transport layer
    mTransport.begin();

    mInputChannel = inChannel;
    mRunningStatus_TX = InvalidType;
    mRunningStatus_RX = InvalidType;

    mPendingMessageIndex = 0;
    mPendingMessageExpectedLength = 0;

    mCurrentRpnNumber  = 0xffff;
    mCurrentNrpnNumber = 0xffff;

    mLastMessageSentTime = Platform::now();

    mMessage.valid   = false;
    mMessage.type    = InvalidType;
    mMessage.channel = 0;
    mMessage.data1   = 0;
    mMessage.data2   = 0;
    mMessage.length  = 0;

    mThruFilterMode = Thru::Full;
    mThruActivated  = mTransport.thruActivated;
}

// -----------------------------------------------------------------------------
//                                 Output
// -----------------------------------------------------------------------------

/*! \addtogroup output
 @{
 */

/*! \brief Send a MIDI message.
\param inMessage    The message

 This method is used when you want to send a Message that has not been constructed
 by the library, but by an external source.
 This method does *not* check against any of the constraints.
 Typically this function is use by MIDI Bridges taking MIDI messages and passing
 them thru.
 */
template<class Transport, class Settings, class Platform>
void MidiInterface<Transport, Settings, Platform>::send(const MidiMessage& inMessage)
{
    if (!inMessage.valid)
        return;

    if (mTransport.beginTransmission(inMessage.type))
    {
        const StatusByte status = getStatus(inMessage.type, inMessage.channel);
        mTransport.write(status);

        if (inMessage.type != MidiType::SystemExclusive)
        {
            if (inMessage.length > 1) mTransport.write(inMessage.data1);
            if (inMessage.length > 2) mTransport.write(inMessage.data2);
        } else
        {
            // sysexArray does not contain the start and end tags
            mTransport.write(MidiType::SystemExclusiveStart);

            for (size_t i = 0; i < inMessage.getSysExSize(); i++)
                mTransport.write(inMessage.sysexArray[i]);

            mTransport.write(MidiType::SystemExclusiveEnd);
        }
    }
    mTransport.endTransmission();
    UpdateLastSentTime();
}


/*! \brief Generate and send a MIDI message from the values given.
 \param inType    The message type (see type defines for reference)
 \param inData1   The first data byte.
 \param inData2   The second data byte (if the message contains only 1 data byte,
 set this one to 0).
 \param inChannel The output channel on which the message will be sent
 (values from 1 to 16). Note: you cannot send to OMNI.

 This is an internal method, use it only if you need to send raw data
 from your code, at your own risks.
 */
template<class Transport, class Settings, class Platform>
void MidiInterface<Transport, Settings, Platform>::send(MidiType inType,
                                               DataByte inData1,
                                               DataByte inData2,
                                               Channel inChannel)
{
    if (inType <= PitchBend)  // Channel messages
    {
        // Then test if channel is valid
        if (inChannel >= MIDI_CHANNEL_OFF  ||
            inChannel == MIDI_CHANNEL_OMNI ||
            inType < 0x80)
        {
            return; // Don't send anything
        }
        // Protection: remove MSBs on data
        inData1 &= 0x7f;
        inData2 &= 0x7f;

        const StatusByte status = getStatus(inType, inChannel);

        if (mTransport.beginTransmission(inType))
        {
            if (Settings::UseRunningStatus)
            {
                if (mRunningStatus_TX != status)
                {
                    // New message, memorise and send header
                    mRunningStatus_TX = status;
                    mTransport.write(mRunningStatus_TX);
                }
            }
            else
            {
                // Don't care about running status, send the status byte.
                mTransport.write(status);
            }

            // Then send data
            mTransport.write(inData1);
            if (inType != ProgramChange && inType != AfterTouchChannel)
            {
                mTransport.write(inData2);
            }

            mTransport.endTransmission();
            UpdateLastSentTime();
        }
    }
    else if (inType >= Clock && inType <= SystemReset)
    {
        sendRealTime(inType); // System Real-time and 1 byte.
    }
}

// -----------------------------------------------------------------------------
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

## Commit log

2022-04-04 Fix a case where sound effects would affect BGM
2022-04-06 Track loop is now working on Scud Race.
2023-07-31 Update README.md
    Add Daytona USA to the list of DSB1 games with optional sound board
2024-01-04 Better calibration for borh original and clone MP3 modules
2024-01-04 Remove a wrong debug message
    [DSB.ino]
2024-01-04 Optimized division - replaced by bitshift
    [DSB.ino]
2024-01-04 Added a patch for Spikeout. Added NL to calibration error message.
    [DSB.ino]
2024-01-04 Added NL to calibration error message.
    [DSB.ino]
2024-10-13 Updated hardware section in Readme. Updated the PCB to remove digipot and simplify build. Uploaded the Kicad 8.0 files.
    [DSBclone.kicad_pcb, DSBclone.kicad_sch]
2024-10-14 Add PCBway project link.
